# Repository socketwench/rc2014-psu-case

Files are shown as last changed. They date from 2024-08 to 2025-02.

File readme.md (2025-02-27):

# Power Base for the RC2014

The [rc2014](https://rc2014.co.uk/) is a retro styled z80 computer you build as a kit. Combined with the [Front Panel Kit](https://z80kits.com/shop/blue-box-front-panel-switch-and-led-for-romwbw/), you have a handsome machine!

But...wouldn't it be *better* if you could also have a little more room? Enough for a power supply, an HDMI adapter, or anything you can mount on a DIN rail?

Look no further!

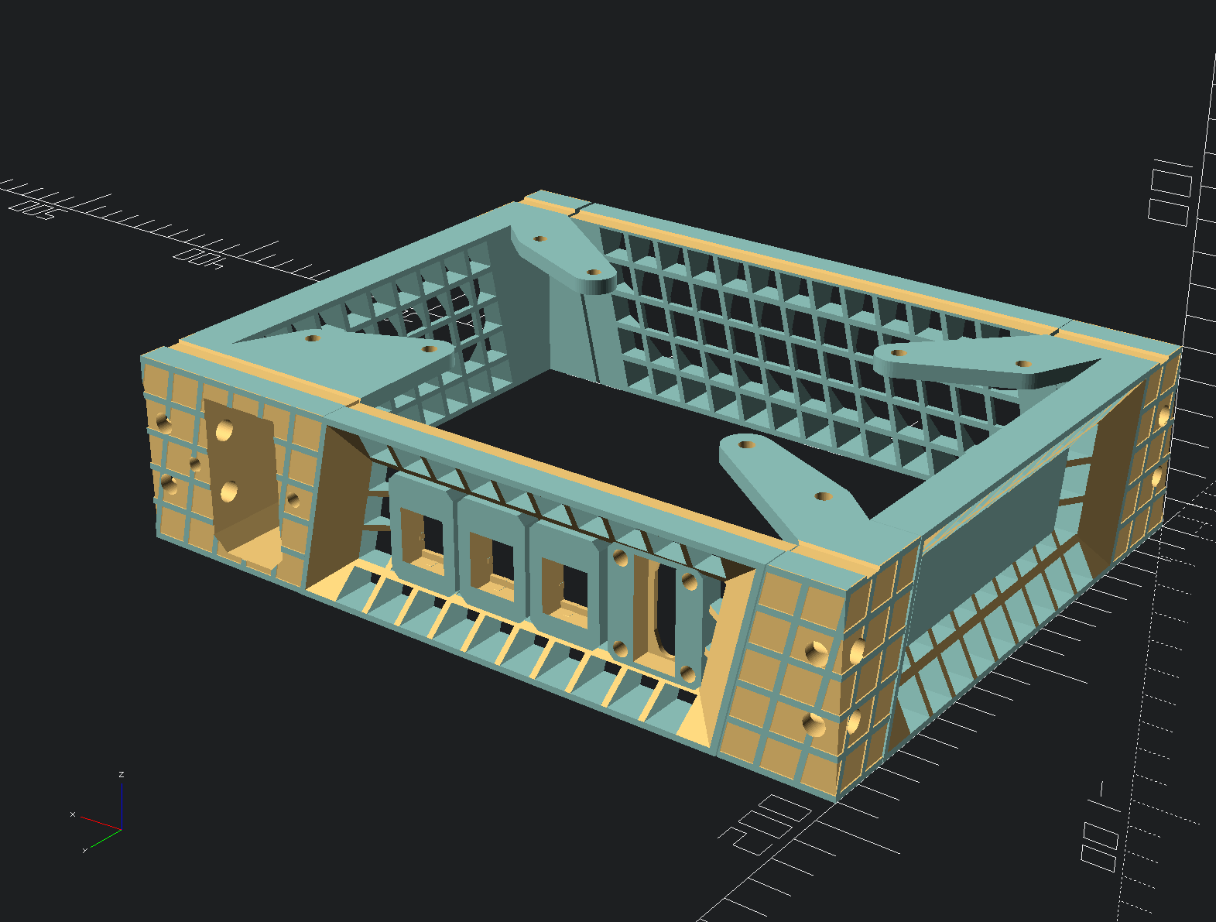
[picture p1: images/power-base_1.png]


## Features

* Dual DIN rails to mount accessories
* Three keystones for added ports
* One IEC power inlet
* One VGA gender changer mountpoint for VGA passthrough
* Threaded inserts for easy assembly and disassembly
* Lots of venting
* rc2014 styling
* Sticker panel!

## Design and motive

Check out the [blog post](https://deninet.com/blog/2024/09/08/printable-expansion-box-rc2014).

## Printing

Print each part in any rigid filament such as PETG, PLA, or ABS. White works wellwith the recommended enclosure!

## Assembly

1. Print all parts, adding threaded inserts where needed.
2. Remove the existing feet from the enclosure.
3. Bolt through the enclosure's existing holes to mount the printed columns.
4. Position the panels, bolting through the columns to secure them.
5. Install the IEC inlet.
6. Install keystones as desired.
7. Install VGA gender changer in the rear-panel pocket, screw down the cover.
8. Install the new feet on the bottom of the columns.

## Gallery

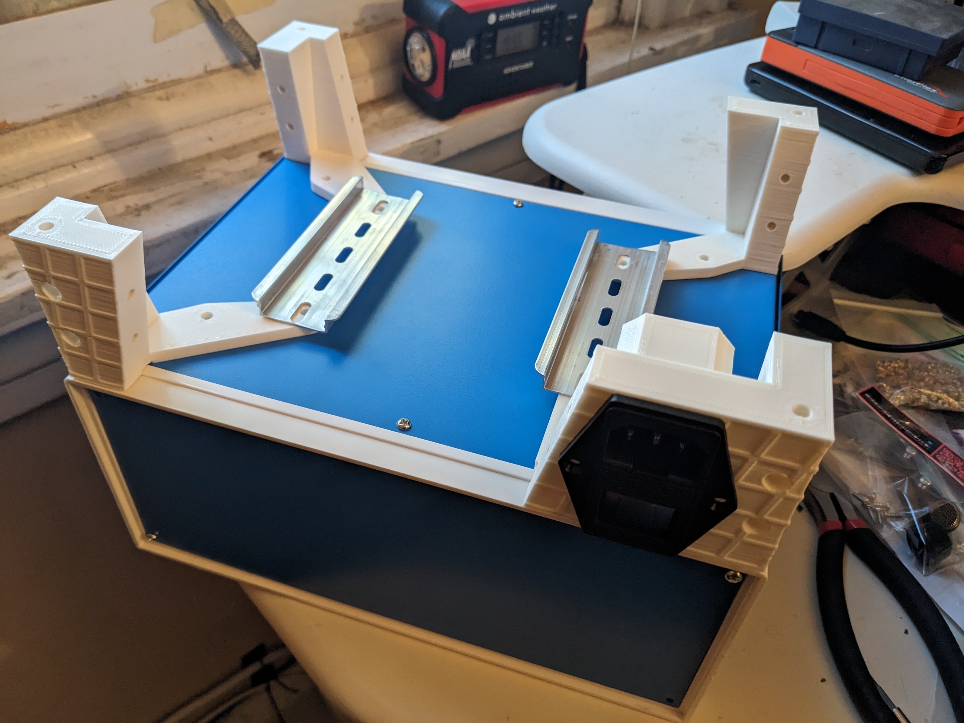
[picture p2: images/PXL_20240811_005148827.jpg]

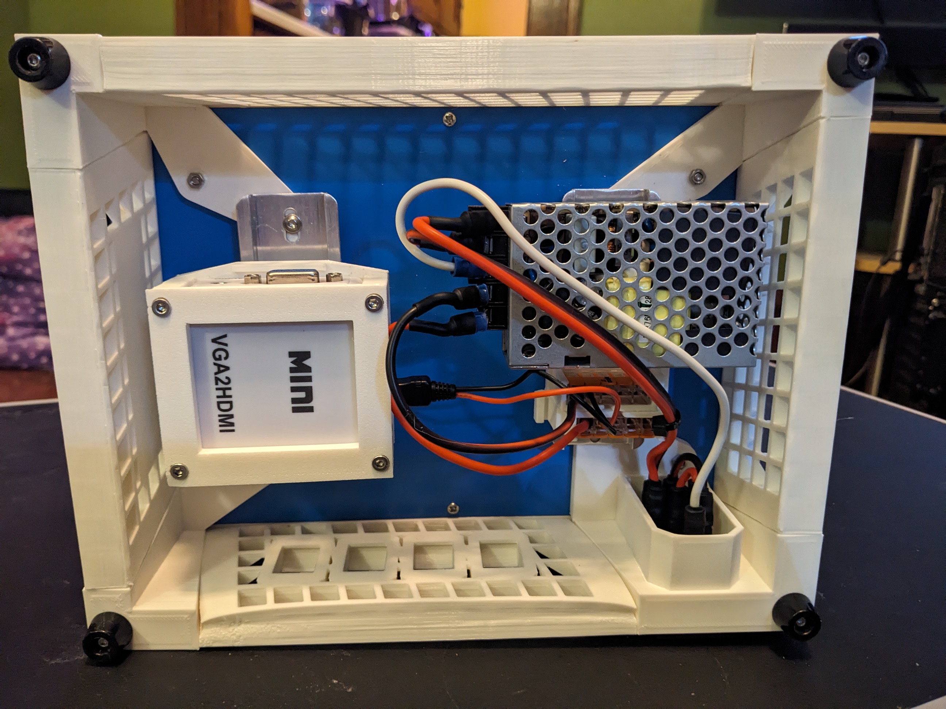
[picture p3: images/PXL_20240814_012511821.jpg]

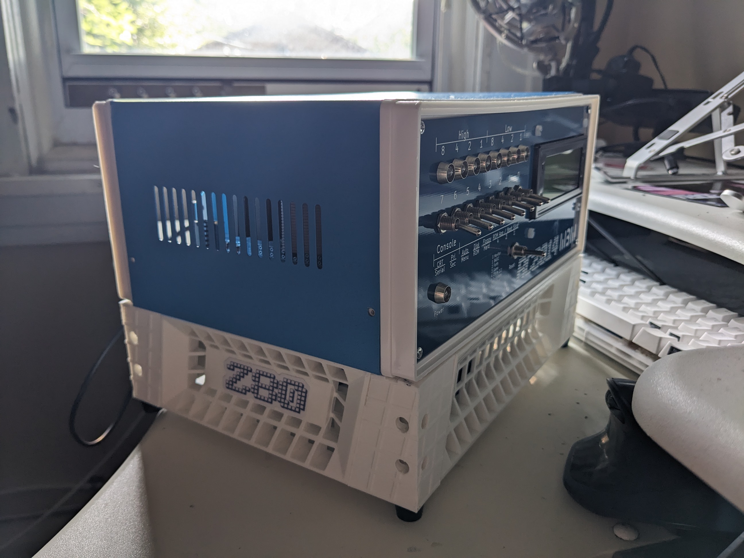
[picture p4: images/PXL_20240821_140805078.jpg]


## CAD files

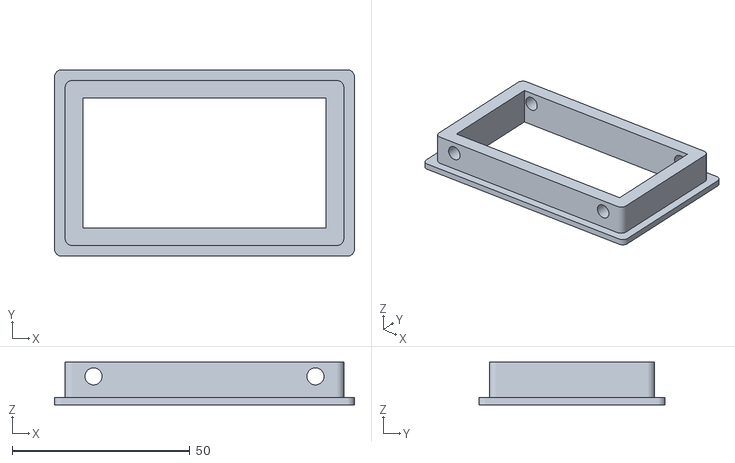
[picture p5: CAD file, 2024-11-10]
bumpOutBoxes/STLs/flange.stl
84.5 x 52.5 x 12.0

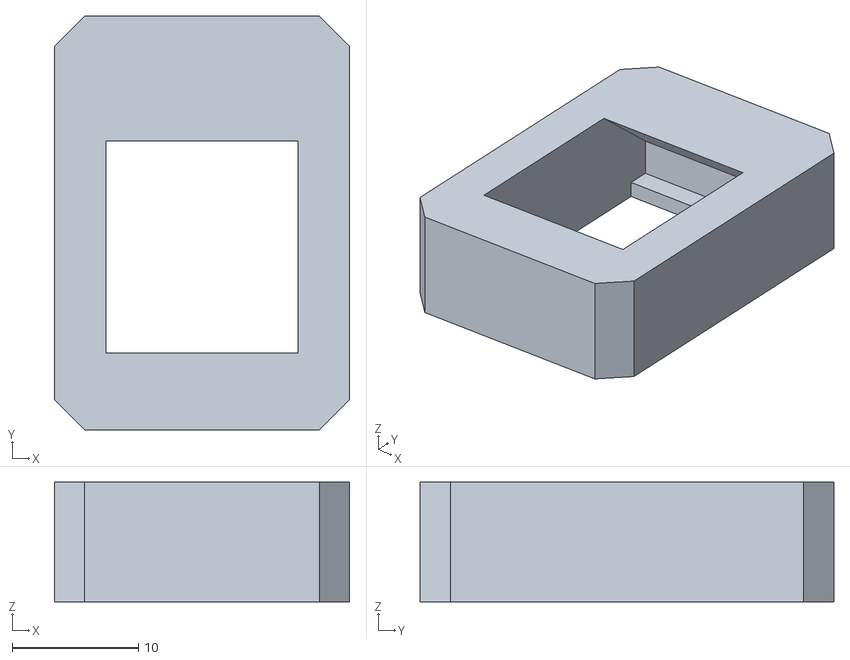
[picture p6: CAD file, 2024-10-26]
keystone/STLs/keystone-port.stl
23.4 x 32.8 x 9.50

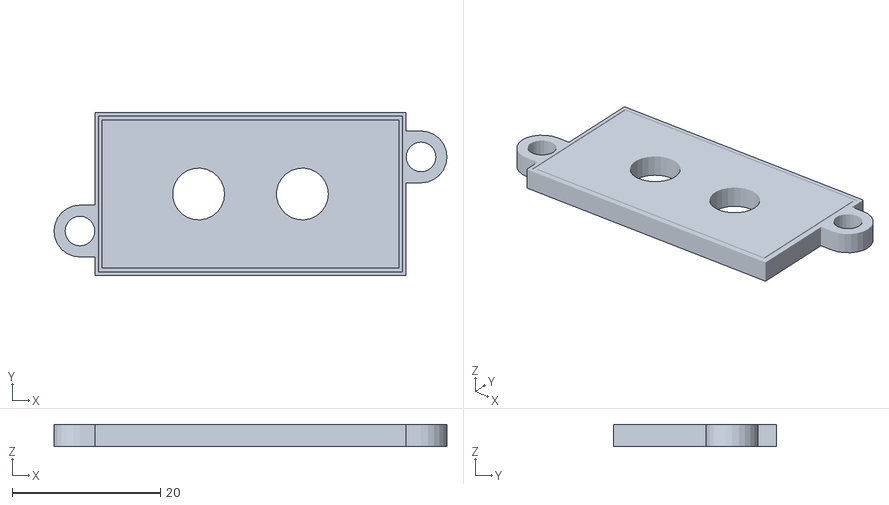
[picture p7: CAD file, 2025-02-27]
rearPanelCovers/STLs/rearPanelCover6mmHoleX2.stl
53.0 x 22.0 x 3.00

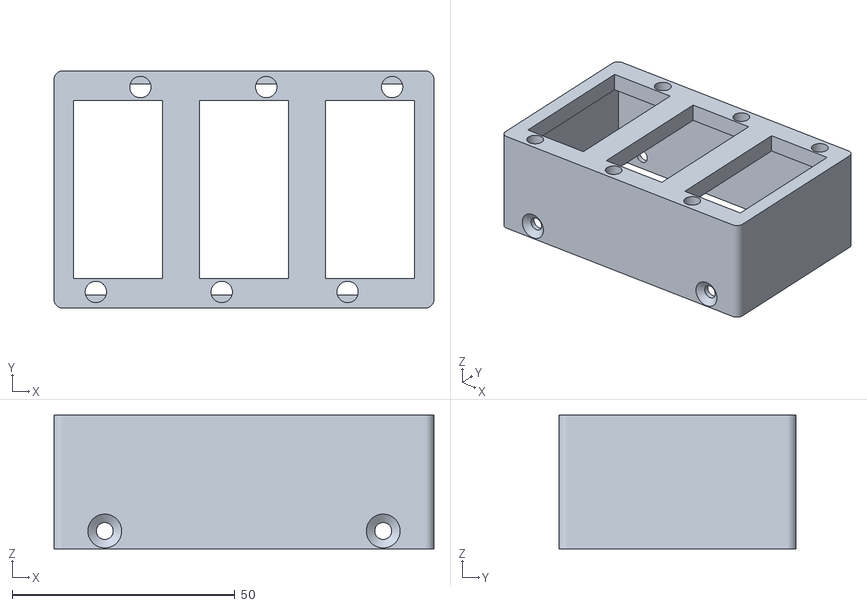
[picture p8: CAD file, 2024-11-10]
bumpOutBoxes/STLs/box.stl
85.3 x 53.3 x 30.0

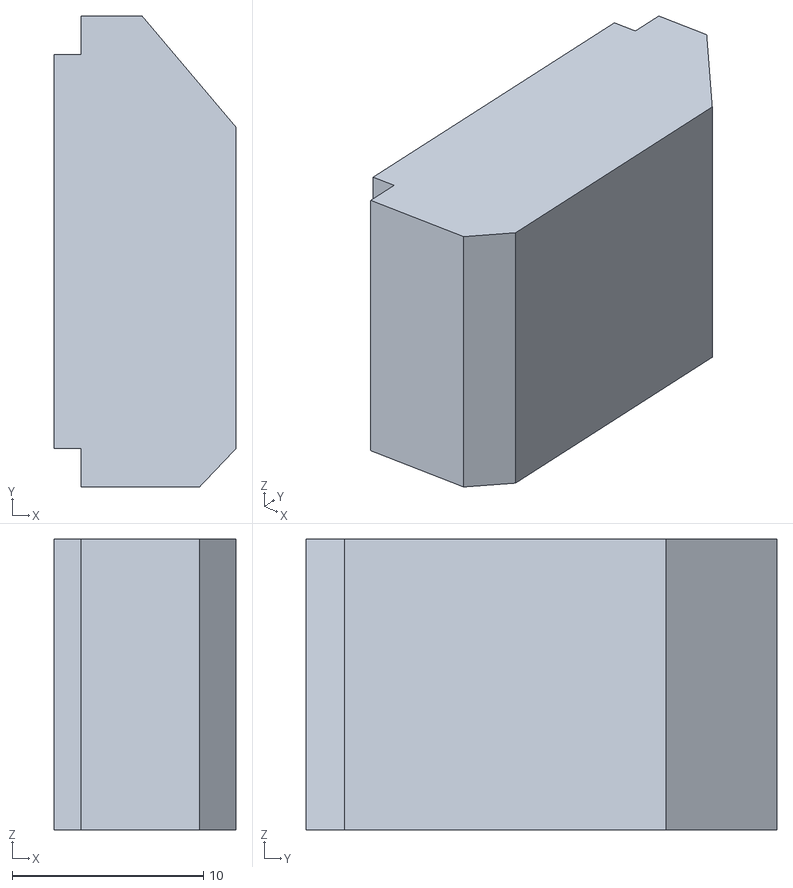
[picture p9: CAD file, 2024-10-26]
keystone/STLs/keystone-cutout.stl
9.50 x 24.6 x 15.2

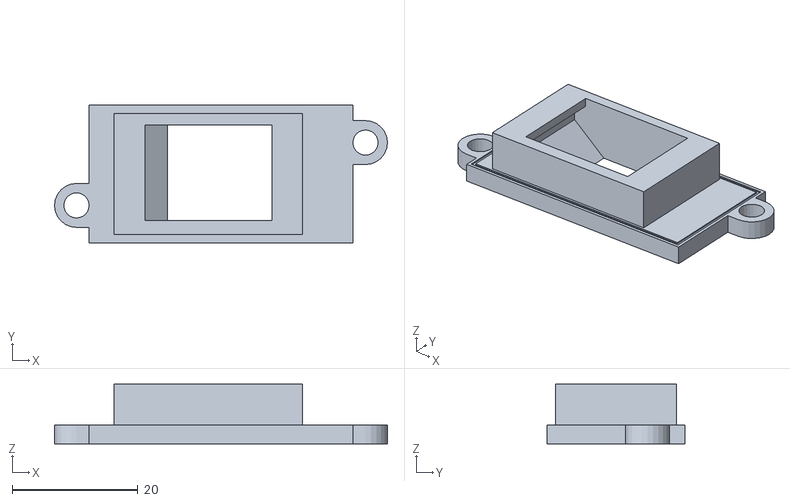
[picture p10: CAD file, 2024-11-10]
rearPanelCovers/STLs/rearPanelCoverKeystone.stl
53.0 x 22.0 x 9.50

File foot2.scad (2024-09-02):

Select = 0; // [0:Preview, 1:leftFrontFoot, 2:rightFrontFoot, 3:leftRearFoot, 4:rightRearFoot,5:frontPanel,6:rearPanel,7:leftPanel,8:rightPanel,9:vgaCover]

bezelDepth=15;
holeX = 31.5;
holeY = 25.4+bezelDepth;
Threaded_insert_width=4.8;
Threaded_insert_height=5;
boltThreadD=3.8;
boltHeadD=Threaded_insert_width+2;

rise = 9;
run = 2;
riseOverRun = rise/run;

//////////////////////////////////////////////////////////////
// Utility Shapes
//////////////////////////////////////////////////////////////

module threadedInsert() {
    cylinder(h=Threaded_insert_height, d=Threaded_insert_width, $fn=50);
}

module bezelCutout(length, width) {    
    linear_extrude(length)
        polygon([
            [0,0],
            [width+.4,0],
            [width,1],
            [0.4,1]
        ]);
}

module columnScrewCutout(totalLength, shankLength) {
    union() {
        cylinder(h=shankLength, d=boltHeadD, $fn=50);
        cylinder(h=totalLength, d=boltThreadD, $fn=50);
        
        // The fudge number here is required, otherwise the
        // shank face gets rendered and the relief is hidden.
        translate([0,0,shankLength-0.01])
            intersection() {
                cylinder(h=shankLength, d=boltHeadD, $fn=50);
                
                cube([boltHeadD,boltThreadD,0.4], center=true);
            }
    }
}

module columnScrewCutoutPair(columnDepth, columnHeight, riseOverRun, shankDepth) {
    
    translate([0,0,(columnHeight/3)*2])
        rotate([0,90,0])
            columnScrewCutout(columnDepth+(columnHeight/riseOverRun),shankDepth+(((columnHeight/3)*2)/riseOverRun));

    translate([0,0,columnHeight/3])
        rotate([0,90,0])
            columnScrewCutout(columnDepth+(columnHeight/riseOverRun),shankDepth+((columnHeight/3)/riseOverRun));
}

module keystoneCutout() {
    linear_extrude(15.2) polygon([
        [0,2],
        [1.4,2],
        [1.4,0],    
        [7.6,0],
        [9.5,2],
        [9.5,18.8],
        [4.6,24.6],
        [1.4,24.6],
        [1.4,22.6],
        [0,22.6],
    ]);
}

module keystonePort() {
    translate([4,4,0]) difference() {
        linear_extrude(9.5)
            offset(delta=4.1, chamfer=true)
                square([15.2,24.6]);
        
        translate([15.2,0,0])
            rotate([0,-90,0])
                keystoneCutout();
    }
}

//////////////////////////////////////////////////////////////
// parallelograms
//////////////////////////////////////////////////////////////

module parallelogram(w, h, riseOverRun) {
    slant = h/riseOverRun;
    polygon([
        [0,0],
        [slant,h],
        [w+slant,h],
        [w,0],
    ]);
}

module parallelogramArray(panelW, panelH, shapeW, shapeH, riseOverRun, spaceX, spaceY) {
    offsetX = shapeW+spaceX;
    offsetY = shapeH+spaceY;
    for(y = [0:offsetY:panelH+offsetY]) {
        translate([y/riseOverRun,0,0]) {
            for(x = [0:offsetX:panelW+offsetX]) {
                translate([x, y, 0]) parallelogram(shapeW, shapeH, riseOverRun);
            }
        }
    }
}

module parallelogramPanel(panelW, panelH, shapeW, shapeH, riseOverRun, spaceX, spaceY) {
    difference() {
        parallelogram(panelW, panelH, riseOverRun);
        
        parallelogramArray(panelW, panelH, shapeW, shapeH, riseOverRun, spaceX, spaceY);
    }
}

module parallelogramFrame(panelW, panelH, riseOverRun, border) {
    difference() {
        parallelogram(panelW, panelH, riseOverRun);
        
        offset(delta=border*-1)
            parallelogram(panelW, panelH, riseOverRun);
    }
}

module parallelogramPanelWithFrame(panelW, panelH, shapeW, shapeH, riseOverRun, spaceX, spaceY, border) {
    
    union() {
        parallelogramFrame(panelW, panelH, riseOverRun, border);
        
        translate([border, border])
            parallelogramPanel(panelW-border, panelH-border, shapeW, shapeH, riseOverRun, spaceX, spaceY);
    }
}

//////////////////////////////////////////////////////////////
// IEC power inlet
//////////////////////////////////////////////////////////////

module iecInletCutoutShape() {
    polygon([
        [-28/2,-49/2],
        [28/2,-49/2],
        [28/2,49/2-4.8],
        [28/2-4.8,49/2],
        [-28/2+4.8,49/2],
        [-28/2,49/2-4.8]
    ]);
}

module iecInletCutout() {
    union() {
        /*
        linear_extrude(0.4)
            polygon([
                [-28/2,-59/2],
                [-49/2,0],
                [-28/2,59/2],
                [28/2,59/2],
                [49/2,0],
                [28/2,-59/2],
            ]);
        */
        translate([-40/2,0,0]) threadedInsert();
        translate([40/2,0,0]) threadedInsert();
        
        translate([0,1.6,0])
            linear_extrude(35)
                iecInletCutoutShape();
    }
}

module iecInletShield(h) {
    translate([0,1.6,0]) difference() {
        linear_extrude(h)
            offset(delta=2) 
                iecInletCutoutShape();
        
        linear_extrude(h) 
            iecInletCutoutShape();
    }
}

//////////////////////////////////////////////////////////////
// Rectangles
//////////////////////////////////////////////////////////////

module rectFrame(panelW, panelH, border) {
    difference() {
        square([panelW, panelH]);
        offset(delta=border*-1)
            square([panelW, panelH]);
    }
}

module roundedRect(rectW, rectH, rectR) {
    hull() {
        translate([rectR, rectR])
            circle(r=rectR, $fn=50);

        translate([rectW-rectR, rectR])
            circle(r=rectR, $fn=50);

        translate([rectR, rectH-rectR])
            circle(r=rectR, $fn=50);

        translate([rectW-rectR, rectH-rectR])
            circle(r=rectR, $fn=50);
    }
}

module chamferRect(rectW, rectH, rectC) {
    offset(delta=rectC, chamfer=true)
        square([rectW-rectC*2, rectH-rectC*2], center=true);
}

//////////////////////////////////////////////////////////////
// Base plates
//////////////////////////////////////////////////////////////

module leftBasePlate(columnWidthX, columnDepthX, columnWidthY, columnDepthY, columnHeight, riseOverRun) {
    
    difference() {
        linear_extrude(Threaded_insert_height) hull() {
            translate([holeX, holeY])
                circle(d=10+Threaded_insert_width, $fn=50);
            
            translate([65, 55])
                circle(d=10+Threaded_insert_width, $fn=50);
            
            polygon([
                [columnDepthY, columnWidthY*1.5],
                [columnWidthX*1.5+(columnHeight/riseOverRun), columnDepthY],
                [columnDepthY, columnWidthY]
            ]);
        }
        
        translate([holeX, holeY, 0]) 
            threadedInsert();
        
        translate([65, 55, 0]) 
            threadedInsert();
    }
}

module rightBasePlate(columnWidthX, columnDepthX, columnWidthY, columnDepthY,columnHeight, riseOverRun) {
    
    mirror([1,0,0]) difference() {
        linear_extrude(Threaded_insert_height) hull() {
            translate([holeX, holeY])
                circle(d=10+Threaded_insert_width, $fn=50);
            
            translate([65, 55])
                circle(d=10+Threaded_insert_width, $fn=50);
            
            polygon([
                [columnDepthX, columnDepthY],
                [columnDepthX, columnDepthY*1.5+(columnHeight/riseOverRun)],
                [columnDepthX*1.5, columnDepthY]
            ]);
        }
        
        translate([holeX, holeY, 0]) 
            threadedInsert();
        
        translate([65, 55, 0]) 
            threadedInsert();
    }
}

//////////////////////////////////////////////////////////////
// Panels
//////////////////////////////////////////////////////////////

module panelThreadedInsertLeft(panelDepth, panelHeight, riseOverRun, bossDiameter) {
    
    translate([((panelHeight/3)*2)/riseOverRun,(panelHeight/3)*2,panelDepth/2])
        rotate([0,90,0])
            union() {
                translate([0,0,(bossDiameter/riseOverRun)/2])
                    threadedInsert();
                translate([0,0,-1*(bossDiameter/riseOverRun)/2])
                    cylinder(h=bossDiameter/riseOverRun, d=bossDiameter, $fn=50);
            }

    translate([(panelHeight/3)/riseOverRun,panelHeight/3,panelDepth/2])
        rotate([0,90,0])
            union() {
                translate([0,0,(bossDiameter/riseOverRun)/2])
                    threadedInsert();
                translate([0,0,-1*(bossDiameter/riseOverRun)/2])
                    cylinder(h=bossDiameter/riseOverRun, d=bossDiameter, $fn=50);
            }
}
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

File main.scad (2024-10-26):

include <keystone/keystone.scad>
include <parallelograms/parallelograms.scad>
include <util/util.scad>
include <basePanels/basePanels.scad>
include <vgaAdapater/vgaAdapter.scad>

Select = 0; // [0:Preview, 1:leftFrontFoot, 2:rightFrontFoot, 3:leftRearFoot, 4:rightRearFoot,5:frontPanel,6:rearPanel,7:leftPanel,8:rightPanel,9:vgaCover]

bezelDepth=15;
holeX = 31.5;
holeY = 25.4+bezelDepth;
Threaded_insert_width=4.8;
Threaded_insert_height=5;
boltThreadD=3.8;
boltHeadD=Threaded_insert_width+2;

rise = 9;
run = 2;
riseOverRun = rise/run;

//////////////////////////////////////////////////////////////
// IEC power inlet
//////////////////////////////////////////////////////////////

module iecInletCutoutShape() {
    polygon([
        [-28/2,-49/2],
        [28/2,-49/2],
        [28/2,49/2-4.8],
        [28/2-4.8,49/2],
        [-28/2+4.8,49/2],
        [-28/2,49/2-4.8]
    ]);
}

module iecInletCutout() {
    union() {
        /*
        linear_extrude(0.4)
            polygon([
                [-28/2,-59/2],
                [-49/2,0],
                [-28/2,59/2],
                [28/2,59/2],
                [49/2,0],
                [28/2,-59/2],
            ]);
        */
        translate([-40/2,0,0]) threadedInsert();
        translate([40/2,0,0]) threadedInsert();
        
        translate([0,1.6,0])
            linear_extrude(35)
                iecInletCutoutShape();
    }
}

module iecInletShield(h) {
    translate([0,1.6,0]) difference() {
        linear_extrude(h)
            offset(delta=2) 
                iecInletCutoutShape();
        
        linear_extrude(h) 
            iecInletCutoutShape();
    }
}

//////////////////////////////////////////////////////////////
// Base plates
//////////////////////////////////////////////////////////////

module leftBasePlate(columnWidthX, columnDepthX, columnWidthY, columnDepthY, columnHeight, riseOverRun) {
    
    difference() {
        linear_extrude(Threaded_insert_height) hull() {
            translate([holeX, holeY])
                circle(d=10+Threaded_insert_width, $fn=50);
            
            translate([65, 55])
                circle(d=10+Threaded_insert_width, $fn=50);
            
            polygon([
                [columnDepthY, columnWidthY*1.5],
                [columnWidthX*1.5+(columnHeight/riseOverRun), columnDepthY],
                [columnDepthY, columnWidthY]
            ]);
        }
        
        translate([holeX, holeY, 0]) 
            threadedInsert();
        
        translate([65, 55, 0]) 
            threadedInsert();
    }
}

module rightBasePlate(columnWidthX, columnDepthX, columnWidthY, columnDepthY,columnHeight, riseOverRun) {
    
    mirror([1,0,0]) difference() {
        linear_extrude(Threaded_insert_height) hull() {
            translate([holeX, holeY])
                circle(d=10+Threaded_insert_width, $fn=50);
            
            translate([65, 55])
                circle(d=10+Threaded_insert_width, $fn=50);
            
            polygon([
                [columnDepthX, columnDepthY],
                [columnDepthX, columnDepthY*1.5+(columnHeight/riseOverRun)],
                [columnDepthX*1.5, columnDepthY]
            ]);
        }
        
        translate([holeX, holeY, 0]) 
            threadedInsert();
        
        translate([65, 55, 0]) 
            threadedInsert();
    }
}

//////////////////////////////////////////////////////////////
// Feet
//////////////////////////////////////////////////////////////

module column(widthX, depthX, widthY, depthY, height, riseOverRun) {
    difference() {
        union() {
            translate([0,depthX,0])
                rotate([90,0,0])
                    linear_extrude(depthX)
                        parallelogram(widthX*1.5, height, riseOverRun);

            translate([0,depthY*1.5+(height/riseOverRun),0])
            rotate([90,0,90])
                linear_extrude(depthY)
                    mirror([1,0,0])
                        parallelogram(widthY*1.5, height, riseOverRun);


            cube([depthX,depthY,height]);
        }
    }
}

module leftFrontFoot() {
    difference() {
        union() {
            translate([0,0,60-Threaded_insert_height])
                leftBasePlate(15,15,15,15,60,riseOverRun);
            column(15,15,15,15,60,riseOverRun);
        }
        
        // Insert for the rubber foot.
        translate([15/2,15/2])
            threadedInsert();
        
        // Screw cutouts
        translate([0,15/2,0])
            columnScrewCutoutPair(15*1.5,60,riseOverRun,15-4);
        translate([15/2,0,60])
            rotate([180,0,90])
                    columnScrewCutoutPair(15*1.5,60,riseOverRun,15-4);
        
        // Cutout for the bezel.
        translate([15*2+(60/riseOverRun),9.4,60])
            rotate([-90,0,90])
                bezelCutout(15*2+(60/riseOverRun), 6);
        
        // Front decoration
        translate([-10.6,0.4,2])
            rotate([90,0,0])
                linear_extrude(0.4) 
                    parallelogramArray(15*1.5, 60, 10.2, 9.6, riseOverRun, 2, 2);
        
        // Side decoration
        translate([0.4,35.4,2])
            rotate([90,0,-90])
                linear_extrude(0.4) 
                    parallelogramArray(15*1.5, 60, 10.2, 9.6, riseOverRun, 2, 2);
    }
}

module rightFrontFoot() {    
    difference() {
        union() {
            translate([0,0,60-Threaded_insert_height])
                rightBasePlate(15,15,15,15,60,riseOverRun);
            
            rotate([0,0,90])
            column(15,15,15,15,60,riseOverRun);
        }

        rotate([0,0,90]) {
            // Insert for the rubber foot.
            translate([15/2,15/2])
                threadedInsert();
                
            // Screw cutouts
            translate([0,15/2,0])
                columnScrewCutoutPair(15*1.5,60,riseOverRun,15-4);
            translate([15/2,0,60])
                rotate([180,0,90])
                        columnScrewCutoutPair(15*1.5,60,riseOverRun,15-4);
        }
        
        // Bezel cutout
        translate([(60/riseOverRun),9.4,60])
            rotate([-90,0,90])
                bezelCutout(15*2+(60/riseOverRun), 6);
    
        // Front decoration
        translate([-35,0.4,2])
            rotate([90,0,0])
                linear_extrude(0.4) 
                    parallelogramArray(15*1.5, 60, 10.2, 9.6, riseOverRun, 2, 2);
        
        // Side decoration
        translate([-0.4,-10.2,2])
            rotate([90,0,90])
                linear_extrude(0.4) 
                    parallelogramArray(15*1.5, 60, 10.2, 9.6, riseOverRun, 2, 2);
    }
    
}

module leftRearFoot() {
    rotate([0,0,180])
        rightFrontFoot();
}

module rightRearFoot() {
    rotate([0,0,180]) difference() {
        union() {
            translate([0,0,60-Threaded_insert_height])
                leftBasePlate(40,15,15,15,60,riseOverRun);
            column(40,15,15,15,60,riseOverRun);
            
            translate([(15*1.5)+(28/2)+3,35,59/2+0.5])
            rotate([90,180,0])
                iecInletShield(35);
        }
        // Insert for the rubber foot.
        translate([15/2,15/2])
            threadedInsert();
                
        // Screw cutouts
        translate([0,15/2,0])
            columnScrewCutoutPair(40*1.5,60,riseOverRun,40*1.5-4);
        translate([15/2,0,60])
            rotate([180,0,90])
                columnScrewCutoutPair(15*1.5,60,riseOverRun,15-4);
        
        
        // Cutout for the bezel.
        translate([40*1.5+(60/riseOverRun),9.4,60])
            rotate([-90,0,90])
                bezelCutout(40*1.5+(60/riseOverRun), 6);

        // Front decoration
        translate([-10.6,0.4,2])
            rotate([90,0,0])
                linear_extrude(0.4) 
                    parallelogramArray(40*1.5, 60, 10.2, 9.6, riseOverRun, 2, 2);
        
        // Side decoration
        translate([0.4,35.4,2])
            rotate([90,0,-90])
                linear_extrude(0.4) 
                    parallelogramArray(15*1.5, 60, 10.2, 9.6, riseOverRun, 2, 2);
    
        translate([(15*1.5)+(28/2)+3,0,59/2+0.5])
            rotate([90,180,180])
                iecInletCutout();
    }
    
}

module frontPanel() {
    difference() {
        panel(183,60,10.2,9.6,riseOverRun,2,2,2,15);
        translate([184.2+60/riseOverRun,60,6])
            rotate([0,90,180])
                bezelCutout(184.2, 6);
    }
}
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

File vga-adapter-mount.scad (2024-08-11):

Select = 0; // [0:Preview, 1:Bottom, 2:Top]

module m3BoltHole(height=6) {
    // Threads
    cylinder(h=height, d = 3.4, $fn = 50);
    
    // Print relief
    translate([0,0,2.5]) {
        intersection() {
            cylinder(h = 0.2, d = 6.2, $fn = 50);
            cube([6.2,3.4,0.2], center=true);
        }
    }
    
    // Socket head
    cylinder(h = 2.5, d = 6.2, $fn = 50);
}

module m3ThreadedInsert() {
    union () {
        cylinder(h=5, d=4.8, $fn=50);

        translate([0,0,5-0.01])
            intersection() {
                cylinder(h=5, d=4.8, $fn=50);
                
                cube([5,4.8/2,0.4], center=true);
            }
    }
}

module baseOutline() {
    points = [
       [20,0],
       [0,25],
       [0,40],
       [70,40],
       [70,25],
       [50,0],
    ];
    
    polygon(points);
}

module baseShape() {
    difference() {
        union() {
            linear_extrude(5) baseOutline();
            translate([20,3,0]) cylinder(h = 5, d=6, $fn=50);
            translate([50,3,0]) cylinder(h = 5, d=6, $fn=50);
        }
        union() {
            translate([22,4,5]) rotate([180,0,0]) m3BoltHole();
            translate([48,4,5]) rotate([180,0,0]) m3BoltHole();
        }
    }
}

module basePost() {
    difference() {
        cube([7.5,10,10]);
        translate([7.5/2,5,0]) cylinder(h = 11, d = 4.8, $fn = 50);
    }
}

module part_bottom() {
    interior_width = 55;
    interior_depth = 62;
    post_width = 7.5;
    post_depth = 10;
    post_height = 10;
    width = interior_width + (post_width * 2);
    depth = interior_depth;
    cutout_width = 15;
    cutout_depth = 10;
    top_height = 6;
    
    insert_offset = ((depth+(4*2))-55)/2;
    
    difference() {
        hull() {
            translate([0,4,0]) cube([width,depth,top_height]);
            translate([20,0,0]) cube([30,2,top_height]);
            translate([20,depth+6,0]) cube([30,2,top_height]);
        }
        
        translate([insert_offset,depth/2+4,0]) m3ThreadedInsert();

        translate([55+insert_offset,depth/2+4,0]) m3ThreadedInsert();
        
        translate([cutout_width, cutout_depth+4, 0])
            cube([width-cutout_width*2, depth-cutout_depth*2, 6]);

    }
    
    translate([20,0,6]) cube([30,2,2]);
    translate([20,depth+6,6]) cube([30,2,2]);
    
    translate([0,4,top_height]) basePost();
            translate([width-post_width,4,top_height]) basePost();
            translate([width-post_width,4+depth-post_depth,top_height]) basePost();
            translate([0,4+depth-post_depth,top_height]) basePost();
}

module topPost() {
    difference() {
        cube([7.5,10,10]);
        translate([7.5/2,5,0]) cylinder(h = 11, d = 3.2, $fn = 50);
    }
}

module part_top() {
    interior_width = 55;
    interior_depth = 62;
    post_width = 7.5;
    post_depth = 10;
    post_height = 10;
    width = interior_width + (post_width * 2);
    depth = interior_depth;
    cutout_width = 10;
    cutout_depth = 10;
    top_height = 5;
    
    difference() {
        union() {
            // Top with cutout.
            difference() {
                cube([width,depth,top_height]);
                translate([cutout_width,cutout_depth,0]) cube([width-cutout_width*2,depth-cutout_depth*2,top_height]);
            }
            
            // Posts. This could probably be a for loop.
            translate([0,0,top_height]) cube([post_width,post_depth,post_height]);
            translate([width-post_width,0,top_height]) cube([post_width,post_depth,post_height]);
            translate([width-post_width,depth-post_depth,top_height]) cube([post_width,post_depth,post_height]);
            translate([0,depth-post_depth,top_height]) cube([post_width,post_depth,post_height]);
        }
        
        translate([post_width/2,post_depth/2,0]) m3BoltHole(height=top_height+post_height);
        translate([width-post_width/2,post_depth/2,0]) m3BoltHole(height=top_height+post_height);
        translate([width-post_width/2,depth-post_depth/2,0]) m3BoltHole(height=top_height+post_height);
        translate([post_width/2,depth-post_depth/2,0]) m3BoltHole(height=top_height+post_height);
    }
}

if (Select==0) {
    part_bottom();
    translate([70,4,32]) rotate([0,180,0]) part_top();
} else if (Select==1) {
    part_bottom();
} else if (Select==2) {
    part_top();
}

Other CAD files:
rearPanelCovers/STLs/rearPanelCover6mmHoleX4.stl
rearPanelCovers/STLs/rearPanelCover6mmHoleX1.stl
rearPanelCovers/STLs/rearPanelCover6mmHoleX3.stl
rearPanelCovers/STLs/rearPanelCoverBlank.stl
vgaAdapter.scad
basePanels/basePanels.scad
basePanels/main.scad
bumpOutBoxes/bumpOutBoxes.scad
bumpOutBoxes/main.scad
keystone/keystone.scad
keystone/main.scad
parallelograms/main.scad
parallelograms/parallelograms.scad
rearPanel/rearPanelBlank.scad
rearPanel/rearPanelKeystone.scad
rearPanelCovers/main.scad
rearPanelCovers/rearPanelCover6mm.scad
rearPanelCovers/rearPanelCoverBlank.scad
rearPanelCovers/rearPanelCoverKeystone.scad
rectangles/rectangles.scad
util/util.scad
vgaAdapater/main.scad
vgaAdapater/vgaAdapter.scad

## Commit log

2024-07-26 Added initial foot SCAD.
    [foot.scad]
2024-08-11 Add full redesign using different methodology.
    [foot2.scad, vga-adapter-mount.scad]
2024-09-02 A completely messy, un-cleaned-up, but functional version.
    [foot.scad, foot.stl, foot2.scad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]
2024-10-13 Add rear panel blank and rear panel keystone covers.
    [keystone.scad, main.scad, rearPanelBlank.scad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]
2024-10-13 Renamed rearPanelCovers directory and files to be more consistent.
    [keystone.scad, main.scad, rearPanelCoverBlank.scad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]
2024-10-26 Refactored several elements into smaller modules with more granular previews for testing.
    [basePanels.scad, foot.scad, foot.stl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]
2024-10-26 Refactored more files.
    [main.scad, rectangles.scad, vgaAdapter.scad]
2024-11-10 Added the Bump-Out-Boxes
    [box.stl, bumpOutBoxes.scad, flange.stl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]
2025-02-27 Tweak keystone files, add switch panel blanks for the rear panel kit.
    [keystone.scad, main.scad, rearPanelCover6mm.scad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]
